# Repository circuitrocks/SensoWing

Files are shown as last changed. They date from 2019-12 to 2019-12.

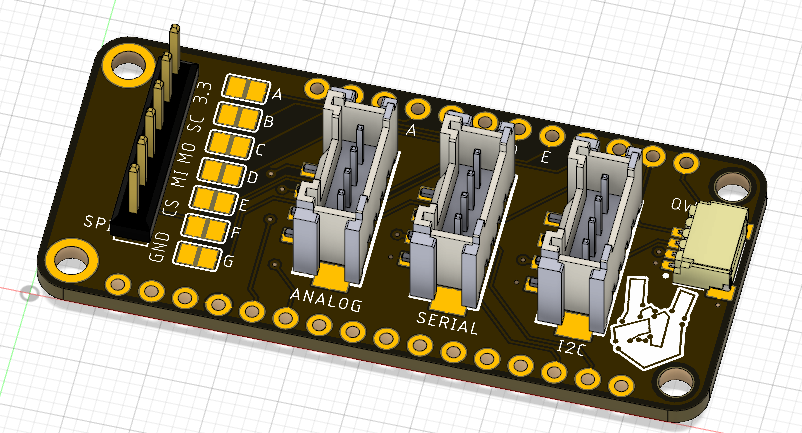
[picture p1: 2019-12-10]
Hardware/Feather-Extension/3D.png

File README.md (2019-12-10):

# Circuitrocks SensoWing

Want to make a quick prototype with some sensors and your Feather boards? Then you might stumble over the same problem we did. 
The Feather system is great as long as you only need to put some Feathers and some Wings together. But how do you connect your sensors, actuators or display?
Well, you can buy a FeatherWing proto board, solder connectors and wires to it and plug your sensors, actuators or display in. But wait, what if your sensor is one of the Sparkfun sensors with a QUICC connector? Good luck with soldering the 1mm pitch QUICC connector to a prototype board.

Don't worry anymore, all these struggles made us think that a Feather with connectors is a good idea.
Our SensoWing has 5 connectors, already wired to the standard I2C, SPI, Serial and Analog ports of the Feathers.
SensoWing carries
- one QUICC connector with I2C
- one Grove connector with I2C
- one Grove connector with Serial
- one Grove connector with 2 Analog inputs or outputs
- one header for SPI bus with the option to connect the SPI CS to any of the free GPIOs.

Sounds good?
What are you waiting for, order some of them, you will find them handy.
If you have some other sensors or stuff without Grove or QUICC connector, don't worry, we have as well some Grove cables in stock that you can solder to your sensors and just plug them into the SensoWing.

The SensoWing comes without headers soldered to it, so you can solder your own choice of headers to it.

## Applications:
Quick prototyping.

## Specifications:
- 1 x 1mm pitch I2C connector compatible with Sparkfuns QUICC standard.
- 1 x I2C connector compatible with Seeed Studio Grove standard.
- 1 x Serial connecter compatible with Seeed Studio Grove standard.
- 1 x Analog in or out connector compatible with Seeed Studio Grove standard.
- 1 x header with SPI bus
- SPI chip select connected to any available GPIO by putting a simple solder bridge

## Technical details:
EagleCAD PCB files, datasheets and more on Github    
Dimensions 2.0”x0.9”x0.28” (51mmx23mmx8mm)

[Check out our tutorial for pinouts and some tips how to use the SensoWing.](https://learn.circuit.rocks/circuitrocks-sensowing)

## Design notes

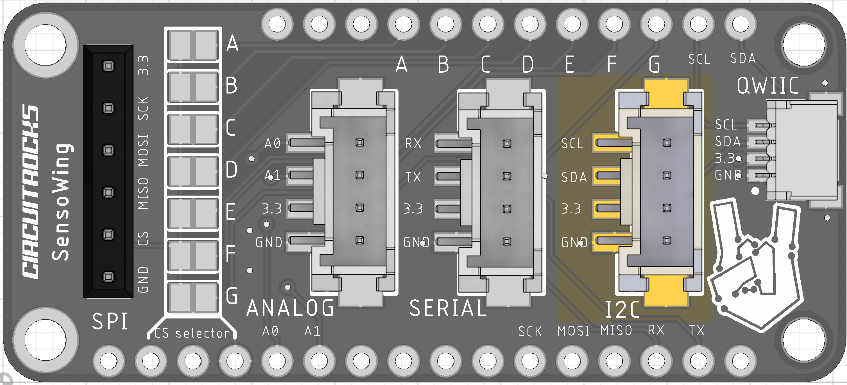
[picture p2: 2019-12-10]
Pictures/Grove I2C.PNG

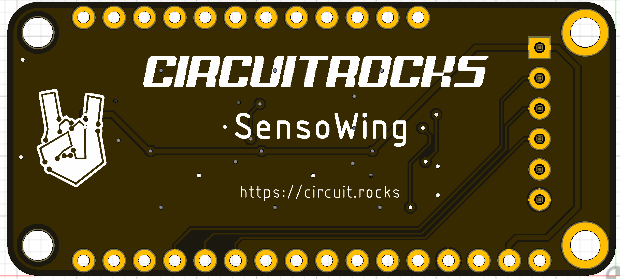
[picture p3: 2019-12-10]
Pictures/Bottom.PNG

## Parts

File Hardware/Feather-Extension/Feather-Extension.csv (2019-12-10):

Qty | Value | Device | Package | Parts | Description | #1_SEEED_LINK | #1_SEEED_SKU | #2_SEEED_LINK | AVAILABILITY | DESCRIPTION | MF | MP | MPN | PACKAGE | POPULARITY | PRICE | VALUE
7 |  | SJ | SJ | A, B, C, D, E, F, G | SMD solder JUMPER |  |  |  |  |  |  |  |  |  | 33
1 | 6p-2.54 | DIP-BLACK-MALE-HEADER(6P-2.54) | H6-2.54 | SPI | 320020078 | https://www.seeedstudio.com/opl.html | 320020078 |  |  |  |  |  | P125-1106A1BS116A1 |  |  |  | 6p-2.54
1 | FEATHERWING | FEATHERWING | FEATHERWING | MS2
3 | H4P-SMD-2.0 | GROVE-CONNECTOR-SMD(4+2P-2.0) | HW4-SMD-2.0 | ANALOG, I2C, SERIAL | 320110030 |  | 320110030 | https://www.seeedstudio.com/opl.html |  |  |  |  |  |  |  |  | H4P-SMD-2.0
1 | SM04B-SRSS-TB(LF)(SN) | SM04B-SRSS-TB(LF)(SN) | JST_SM04B-SRSS-TB(LF)(SN) | QWIIC | SH Series 1.0 mm Pitch 2 Position Single Row Side Entry Shrouded Header |  | JST SM04B-SRSS-TB_LF_SN | https://order.jst-mfg.com/InternetShop/app/index.php?back=2&product=67585401&jgcd=0 | Unavailable | SH Series 1.0 mm Pitch 2 Position Single Row Side Entry Shrouded Header | JST Sales | SM04B-SRSS-TB_LF__SN_ |  | None |  | None

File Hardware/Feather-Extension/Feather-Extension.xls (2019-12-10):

Designator | Manufacturer Part Number or Seeed SKU | Qty | Link | Qty | Value | Device | Package | Parts | Description | #1_SEEED_LINK | #1_SEEED_SKU | #2_SEEED_LINK | AVAILABILITY | DESCRIPTION | MF | MP | MPN | PACKAGE | POPULARITY | PRICE | VALUE
SPI | 320020078 | 1 |  | 1 | 6p-2.54 | DIP-BLACK-MALE-HEADER(6P-2.54) | H6-2.54 | SPI | 320020078 | https://www.seeedstudio.com/opl.html | 320020078 |  |  |  |  |  | P125-1106A1BS116A1 |  |  |  | 6p-2.54
ANALOG, I2C, SERIAL | 320110030 | 3 | https://www.seeedstudio.com/opl.html | 3 | H4P-SMD-2.0 | GROVE-CONNECTOR-SMD(4+2P-2.0) | HW4-SMD-2.0 | ANALOG, I2C, SERIAL | 320110030 |  | 320110030 | https://www.seeedstudio.com/opl.html |  |  |  |  |  |  |  |  | H4P-SMD-2.0
QWIIC | JST SM04B-SRSS-TB_LF_SN | 1 | https://order.jst-mfg.com/InternetShop/app/index.php?back=2&product=67585401&jgcd=0 | 1 | SM04B-SRSS-TB(LF)(SN) | SM04B-SRSS-TB(LF)(SN) | JST_SM04B-SRSS-TB(LF)(SN) | QWIIC | SH Series 1.0 mm Pitch 2 Position Single Row Side Entry Shrouded Header |  | JST SM04B-SRSS-TB_LF_SN | https://order.jst-mfg.com/InternetShop/app/index.php?back=2&product=67585401&jgcd=0 | Unavailable | SH Series 1.0 mm Pitch 2 Position Single Row Side Entry Shrouded Header | JST Sales | SM04B-SRSS-TB_LF__SN_ |  | None |  | None

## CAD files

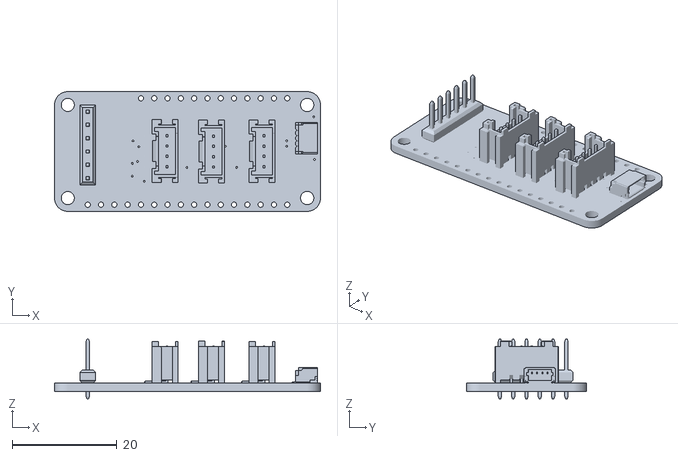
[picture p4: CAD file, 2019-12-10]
3D/SensoWing.stl
50.8 x 22.9 x 11.4

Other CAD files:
3D/SensoWing.f3d

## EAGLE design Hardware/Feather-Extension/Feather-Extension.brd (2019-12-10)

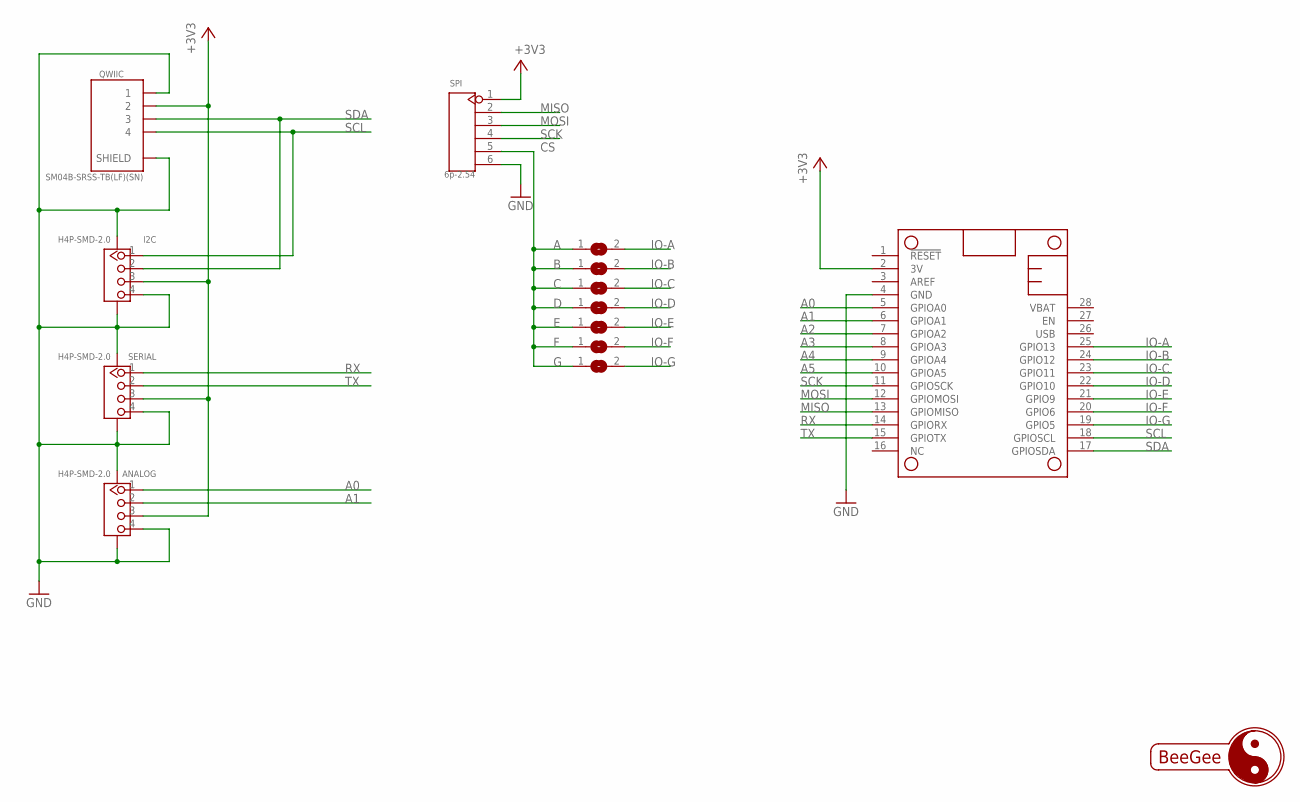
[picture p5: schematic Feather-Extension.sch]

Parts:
A: SJ
ANALOG: H4P-SMD-2.0; HW4-SMD-2.0
B: SJ
C: SJ
D: SJ
E: SJ
F: SJ
G: SJ
I2C: H4P-SMD-2.0; HW4-SMD-2.0
MS2: FEATHERWING
QWIIC: SM04B-SRSS-TB(LF)(SN); JST_SM04B-SRSS-TB(LF)(SN)
SERIAL: H4P-SMD-2.0; HW4-SMD-2.0
SPI: 6p-2.54; H6-2.54

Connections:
+3V3: ANALOG.3, I2C.3, MS2.2 (3V), QWIIC.2, SERIAL.3, SPI.1
A0: ANALOG.1, MS2.5 (GPIOA0)
A1: ANALOG.2, MS2.6 (GPIOA1)
A2: MS2.7 (GPIOA2)
A3: MS2.8 (GPIOA3)
A4: MS2.9 (GPIOA4)
A5: MS2.10 (GPIOA5)
CS: A.1, B.1, C.1, D.1, E.1, F.1, G.1, SPI.5
GND: ANALOG.4, ANALOG.SS1, ANALOG.SS2, I2C.4, I2C.SS1, I2C.SS2, MS2.4 (GND), QWIIC.1, QWIIC.S1 (SHIELD), QWIIC.S2 (SHIELD), SERIAL.4, SERIAL.SS1, SERIAL.SS2, SPI.6
IO-A: A.2, MS2.25 (GPIO13)
IO-B: B.2, MS2.24 (GPIO12)
IO-C: C.2, MS2.23 (GPIO11)
IO-D: D.2, MS2.22 (GPIO10)
IO-E: E.2, MS2.21 (GPIO9)
IO-F: F.2, MS2.20 (GPIO6)
IO-G: G.2, MS2.19 (GPIO5)
MISO: MS2.13 (GPIOMISO), SPI.2
MOSI: MS2.12 (GPIOMOSI), SPI.3
RX: MS2.14 (GPIORX), SERIAL.1
SCK: MS2.11 (GPIOSCK), SPI.4
SCL: I2C.1, MS2.18 (GPIOSCL), QWIIC.4
SDA: I2C.2, MS2.17 (GPIOSDA), QWIIC.3
TX: MS2.15 (GPIOTX), SERIAL.2

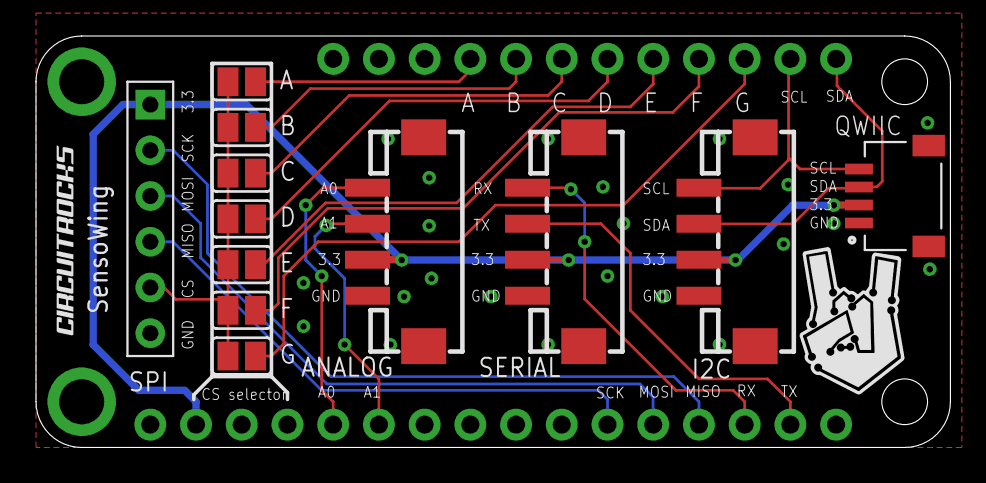
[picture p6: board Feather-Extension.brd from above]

Board: 2 copper layers, 50.8 x 22.9 mm, 13 parts (0 on the bottom side), 19 nets.

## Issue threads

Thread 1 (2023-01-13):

Feature request: Format SPI pins in Breakout garden format

samuk, 2023-01-13:
https://shop.pimoroni.com/collections/breakout-garden is yet another connection system.

It seems like if you re-ordered the SPI GPIO users could plug/solder one  of these: https://shop.pimoroni.com/products/spi-breakout-garden-extender-kit?variant=27886651342931

Bonus points if you could squeeze the 5pin I2C in too, but this adaptor would already work with the Qwiic: https://shop.pimoroni.com/products/stemma-qt-qwiic-to-breakout-garden-adapter?variant=39308432703571
